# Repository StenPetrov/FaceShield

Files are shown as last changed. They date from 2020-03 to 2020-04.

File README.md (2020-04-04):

# FaceShield

This is a design for a lightweight face shield, made from laser-cut clear sheet plastic and a specialized 3D-printed screw. The design is suitable for fast production and is comfortable to wear with securely held elastic band.

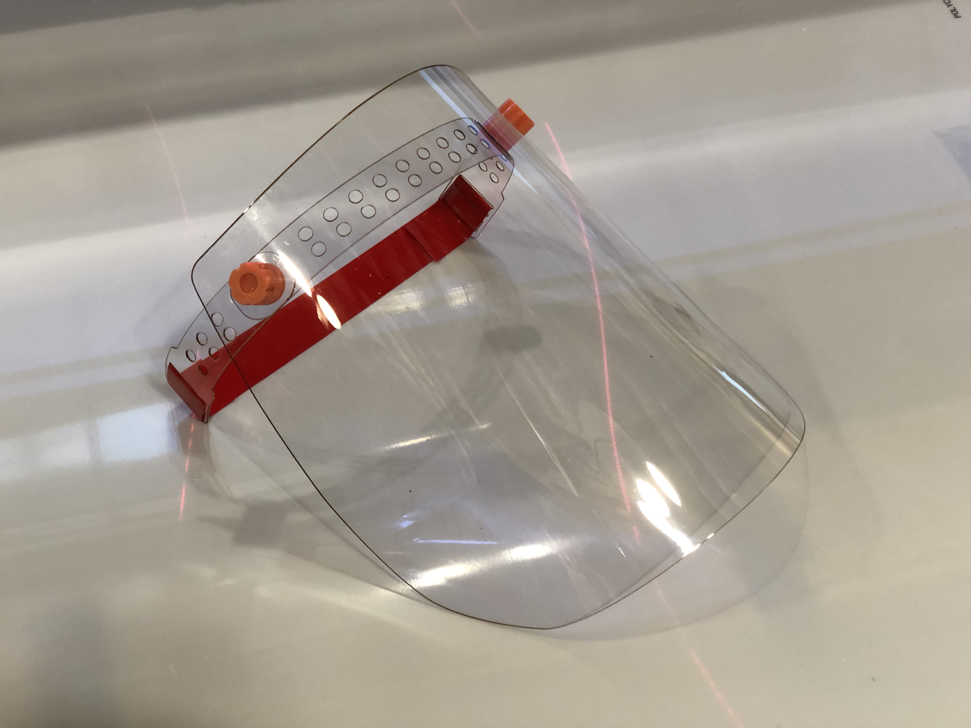
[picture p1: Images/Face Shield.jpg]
Face Shield


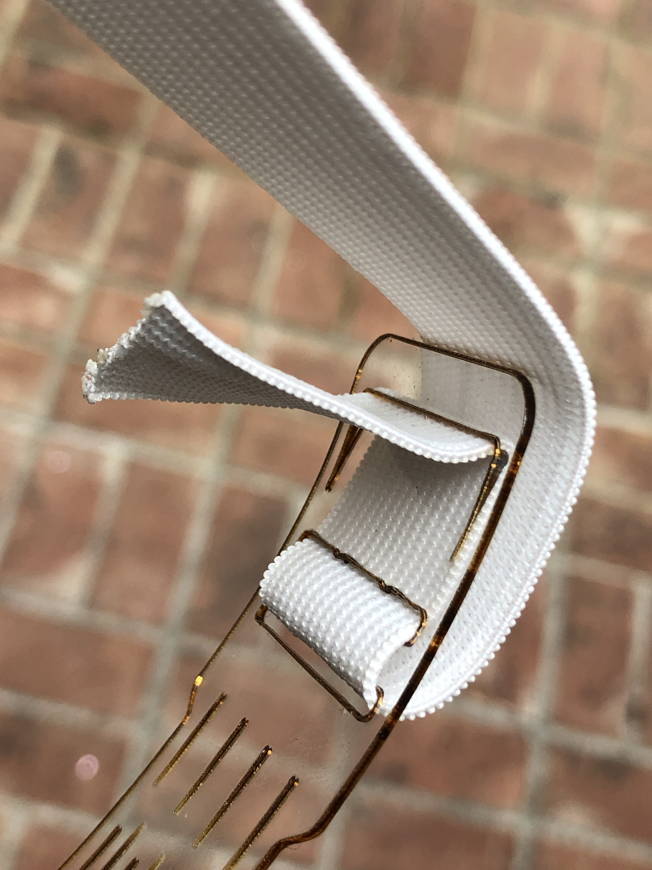
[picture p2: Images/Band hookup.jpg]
Elastic band


The shield was approved for use by Seattle Overlake hospital.

Popular [Prusa Face Shield](https://www.prusa3d.com/covid19/) requires 2+ hours to 3D print, with large nozzle and high speeds. It is comfortable to wear\* due to its wide band. There are designs with narrow head band, which print much faster (15-30 min) but aren't as comfortable with the narrow band.

**WARNING:** DO NOT CUT POLYCARBONATE OR ANY CHLORINE-CONTAINING PLASTICS WITHOUT PROPER VENTILATION. THE FUMES ARE TOXIC

Sheet plastic can be polystyrene or polycarbonate\*, 0.015" to 0.030"\* in thickness and 12" (30cm) square in size. Other materials and thicknesses may be usable. The sheet should comply nicely with the curved shape but not fold freely.
PETG\* 3D-printed specialized screw can be replaced with rivets if a 3D printer is not available.
1" (25mm) elastic band, about 12" (30cm) is used to keep the face shield tight, yet comfortable.
1" rescue tape is used for the elastic band as it is readily available, non-porous and temperature resistant so it is easy to clean in a dishwasher or with bleach.

Feel free to fork or contribute in any way. Feedback is welcome.

---
\*: tested

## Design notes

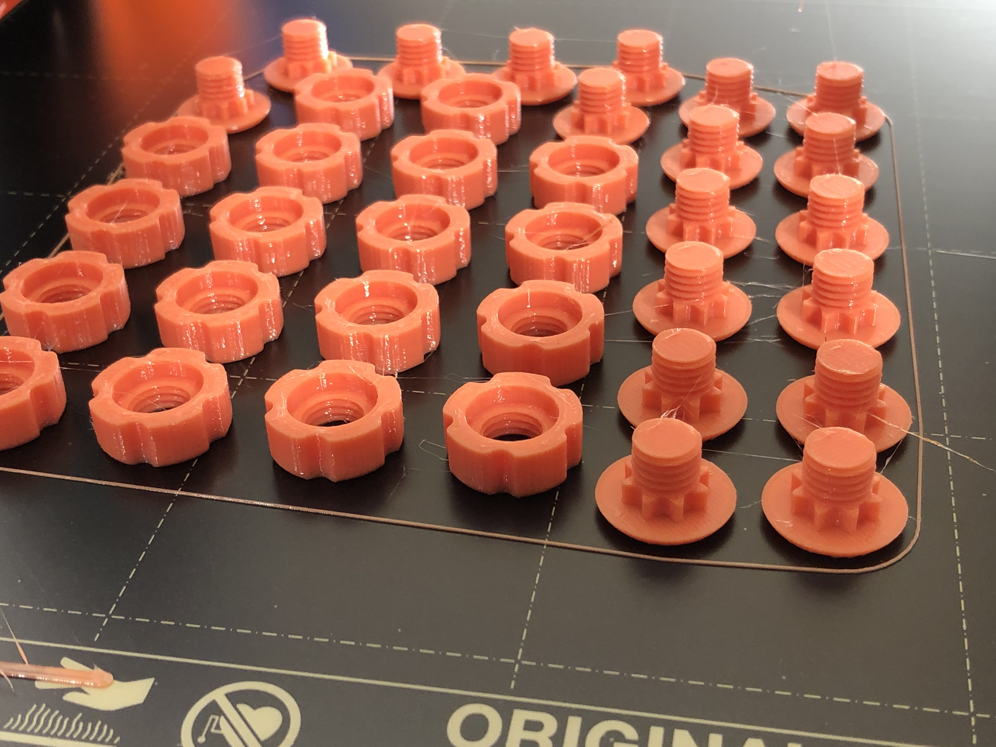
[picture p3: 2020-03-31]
Images/Specialized Screw.jpg

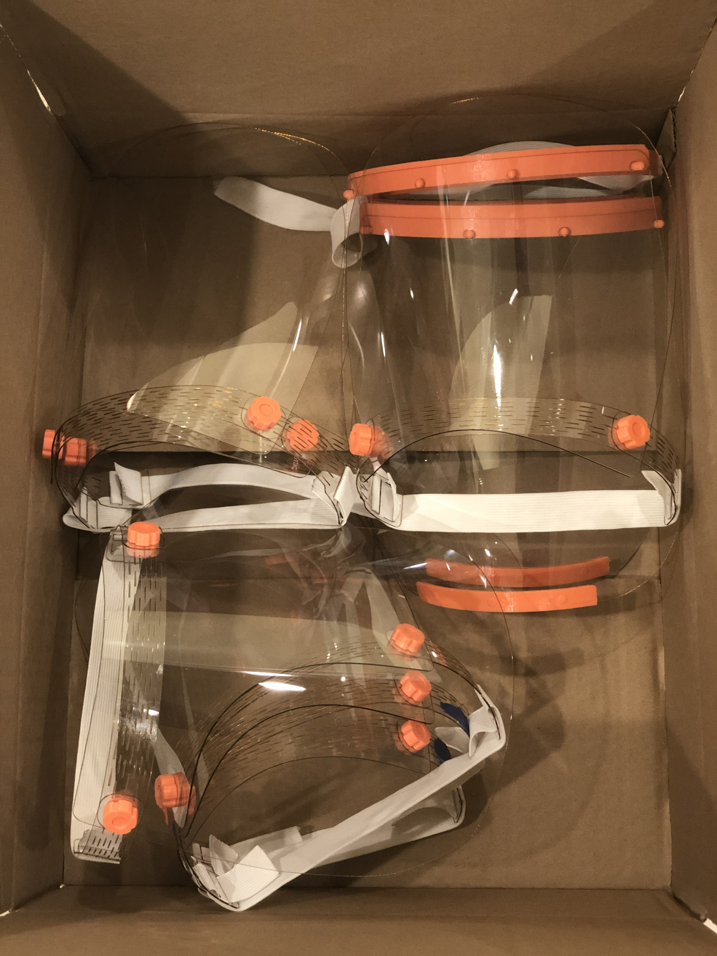
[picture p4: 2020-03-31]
Images/Package.jpg

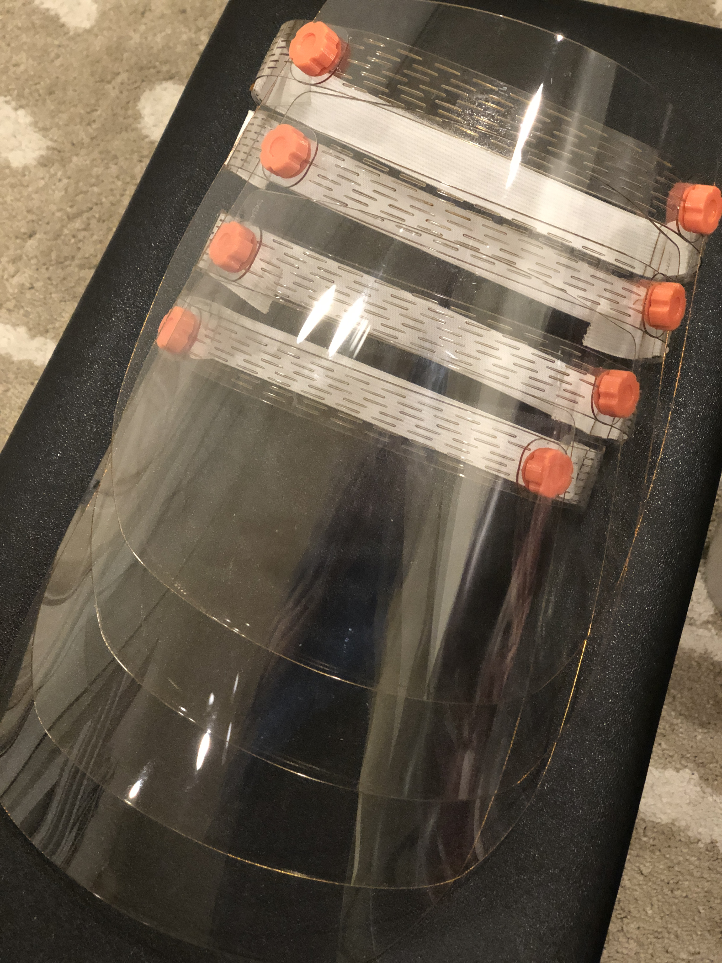
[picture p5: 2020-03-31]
Images/Four Face Shields.jpg

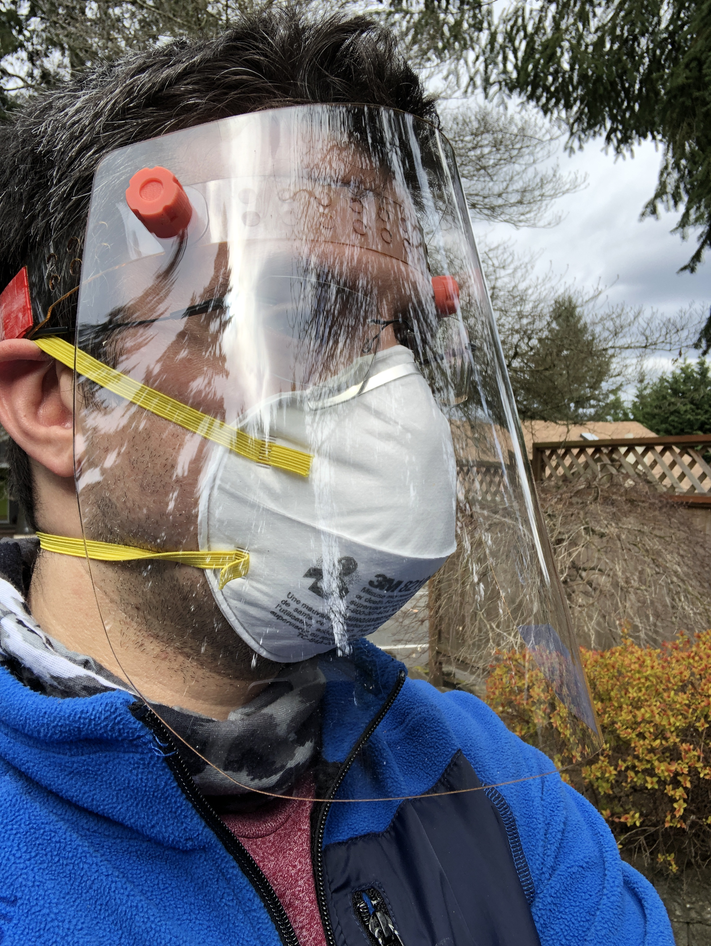
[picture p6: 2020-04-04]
Images/Worn with mask and glasses 2.jpg

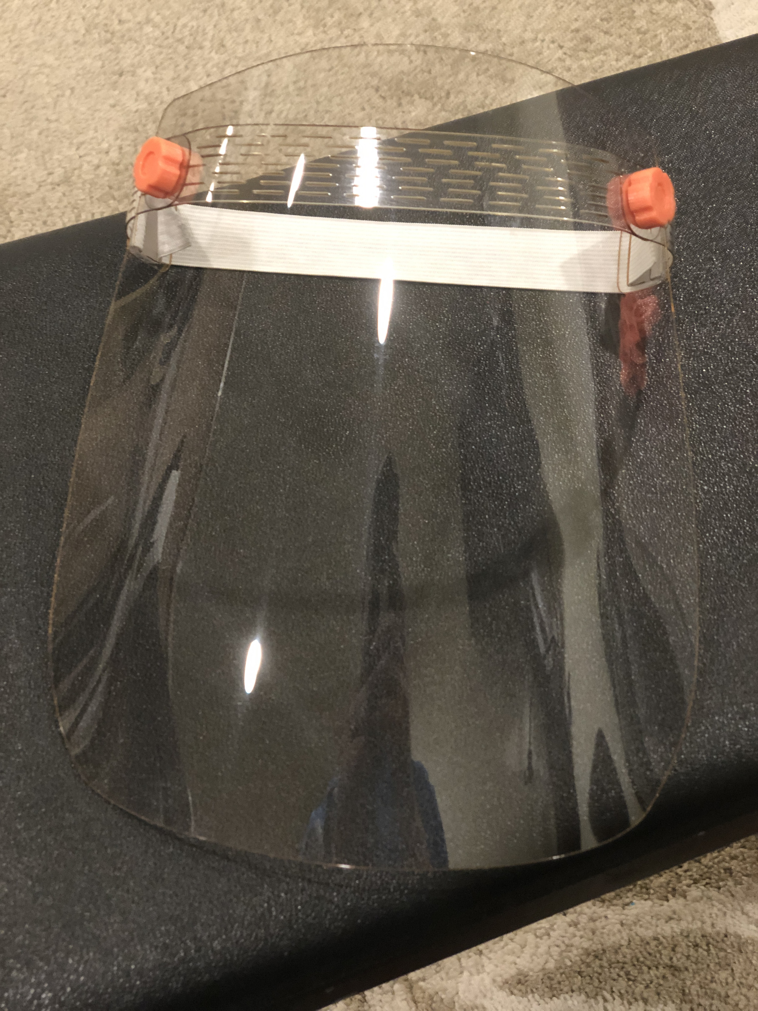
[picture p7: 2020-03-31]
Images/Face Shield Prototype.jpg

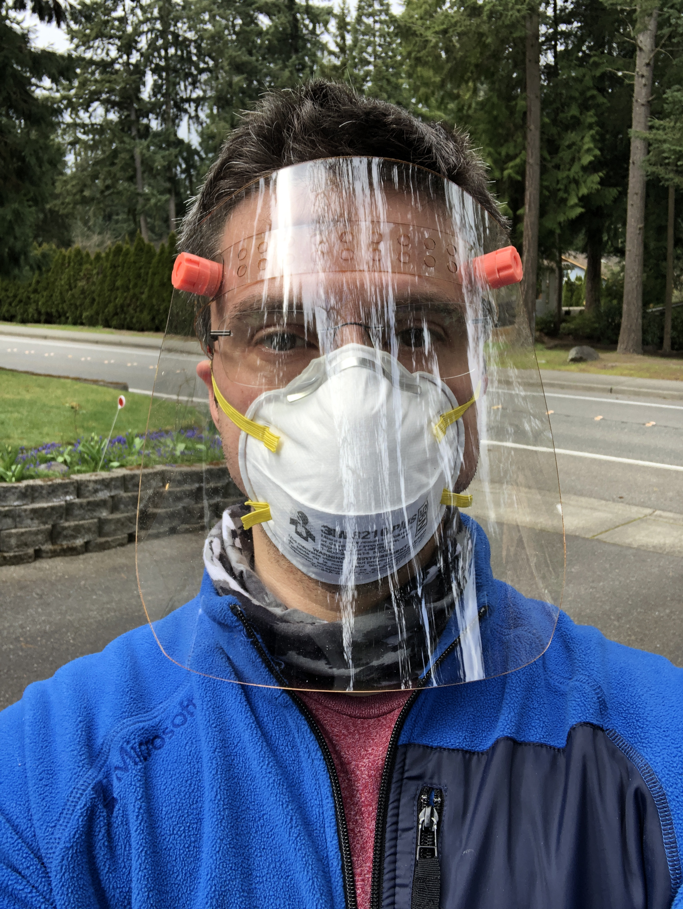
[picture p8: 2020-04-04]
Images/Worn with mask and glasses 1.jpg

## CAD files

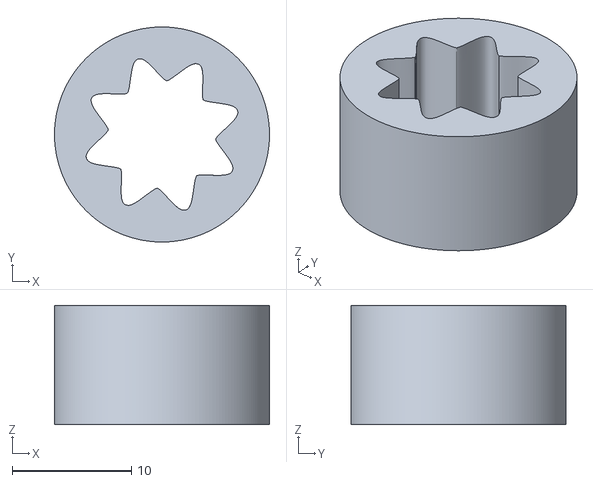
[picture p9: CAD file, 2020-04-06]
3D Parts/Rev 2/10 mm Spacer.stl
18.0 x 18.0 x 10.0

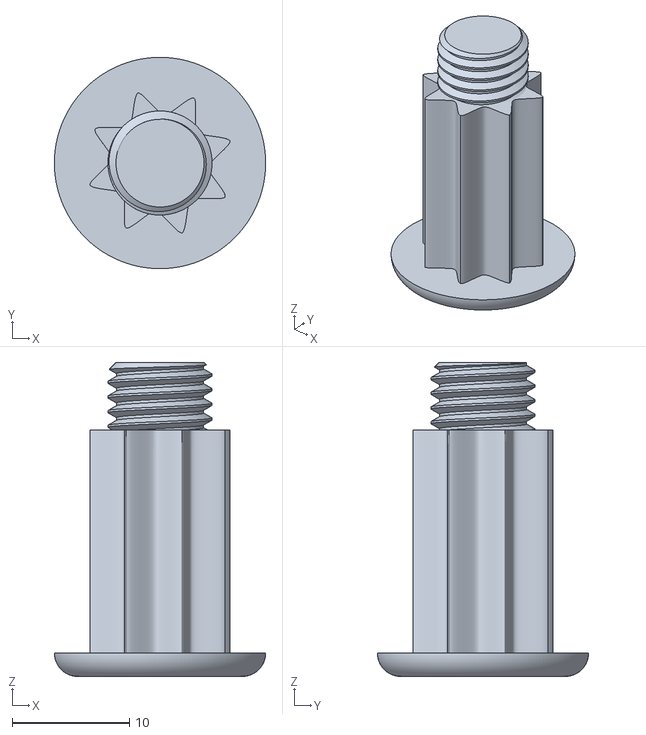
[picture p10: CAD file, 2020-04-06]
3D Parts/Rev 2/15 mm Insert.stl
18.0 x 18.0 x 26.8

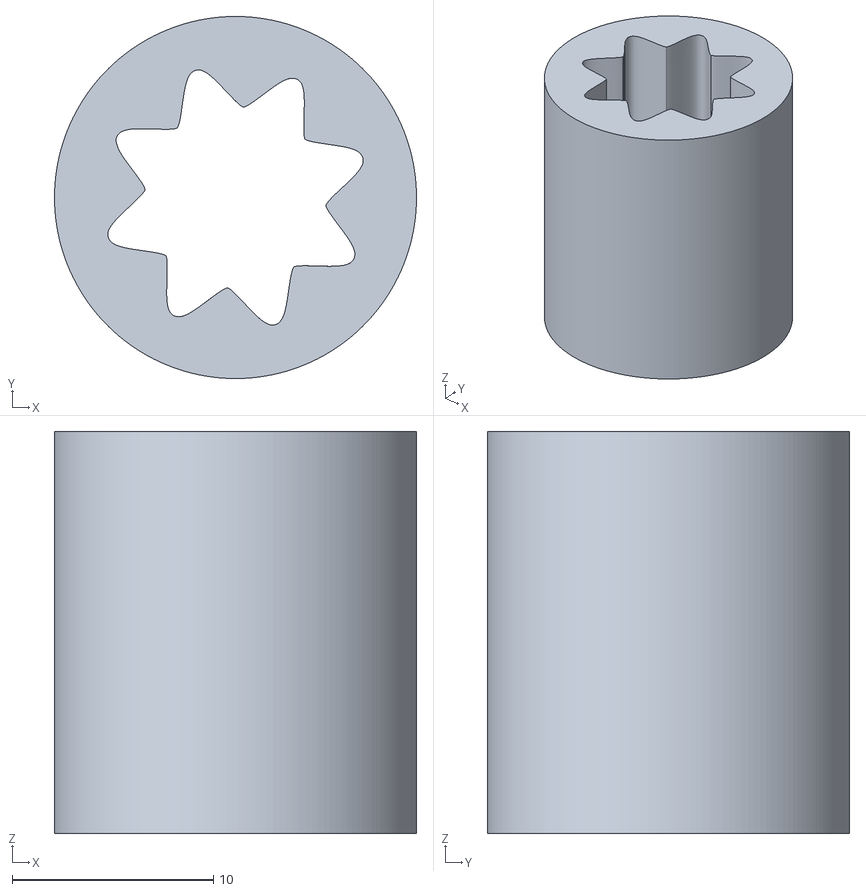
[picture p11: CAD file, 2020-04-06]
3D Parts/Rev 2/20 mm Spacer.stl
18.0 x 18.0 x 20.0

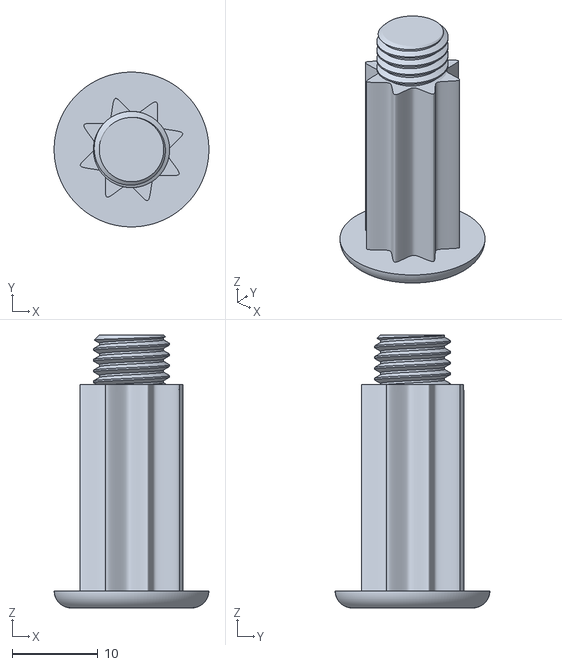
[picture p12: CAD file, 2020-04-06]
3D Parts/Rev 2/20 mm Insert.stl
18.0 x 18.0 x 31.7

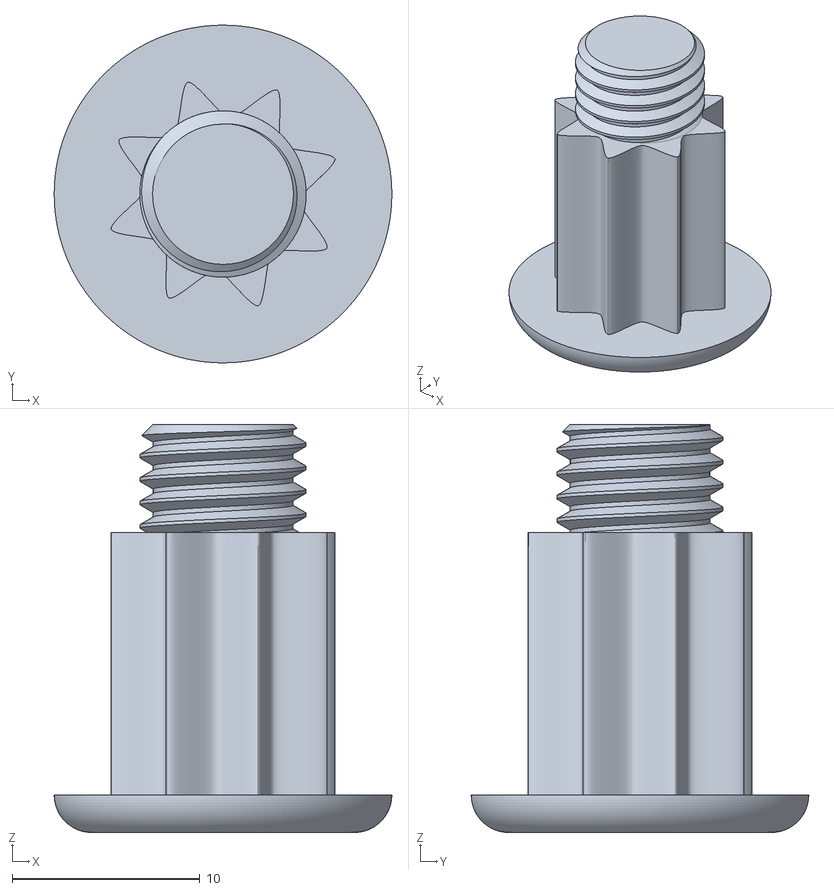
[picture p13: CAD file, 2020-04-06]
3D Parts/Rev 2/10 mm Insert.stl
18.0 x 18.0 x 21.8

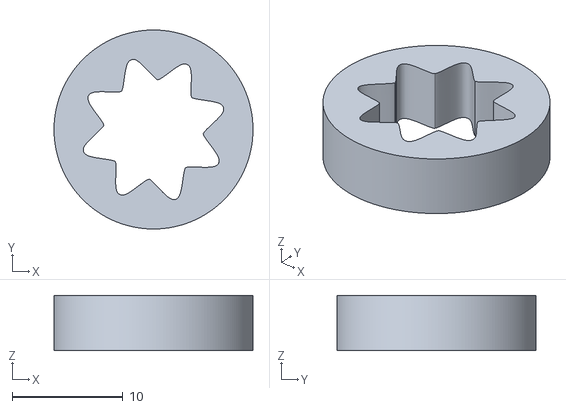
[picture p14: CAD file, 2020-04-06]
3D Parts/Rev 2/5 mm Spacer.stl
18.0 x 18.0 x 5.00

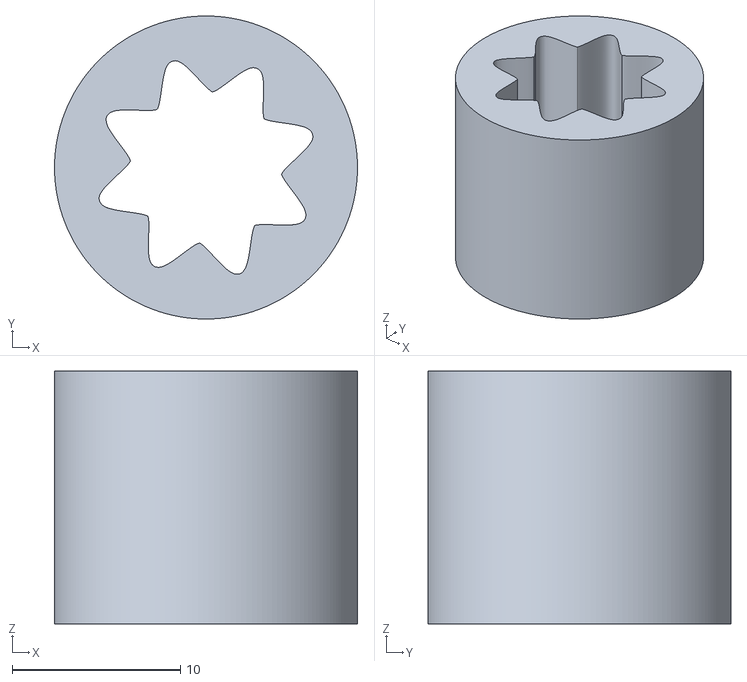
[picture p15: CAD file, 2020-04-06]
3D Parts/Rev 2/15 mm Spacer.stl
18.0 x 18.0 x 15.0

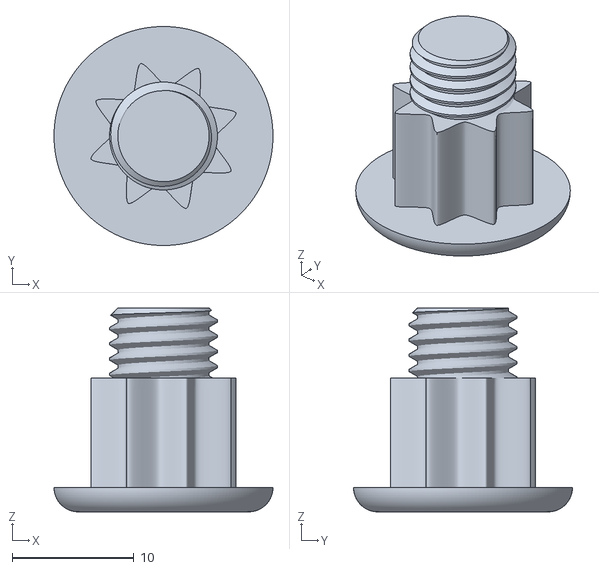
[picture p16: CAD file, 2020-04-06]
3D Parts/Rev 2/5 mm Insert.stl
18.0 x 18.0 x 16.8

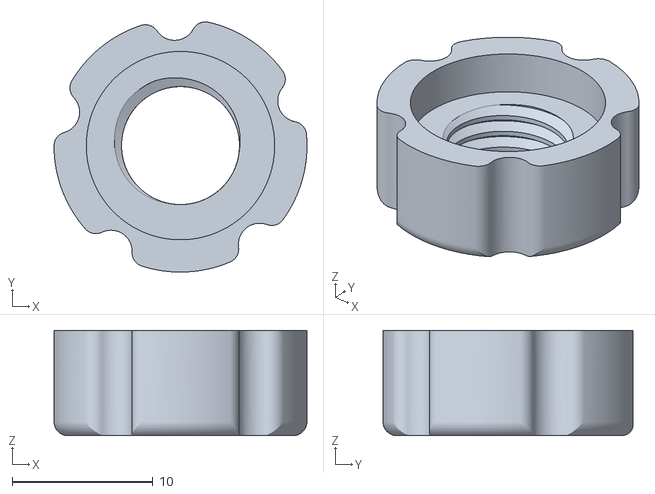
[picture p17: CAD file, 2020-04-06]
3D Parts/Rev 2/Nut - 8 pcnt tolerance.stl
18.0 x 17.8 x 7.50

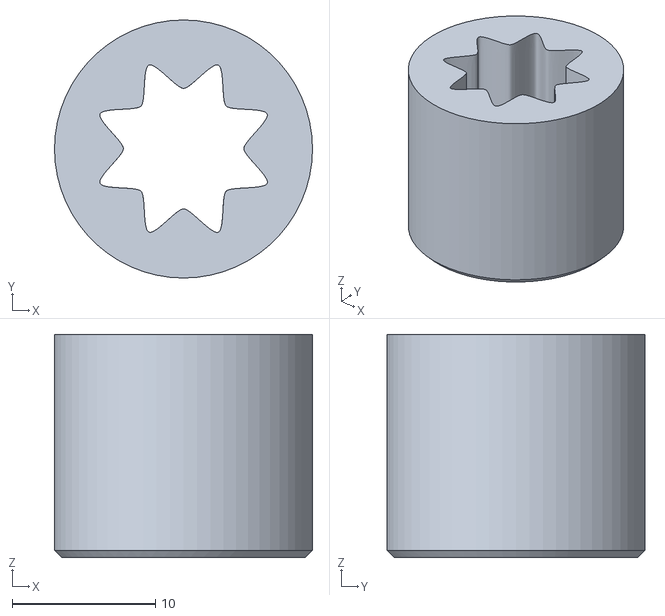
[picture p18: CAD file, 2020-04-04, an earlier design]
3D Parts/Rev 1/Spacer 15mm.stl
18.0 x 18.0 x 15.6

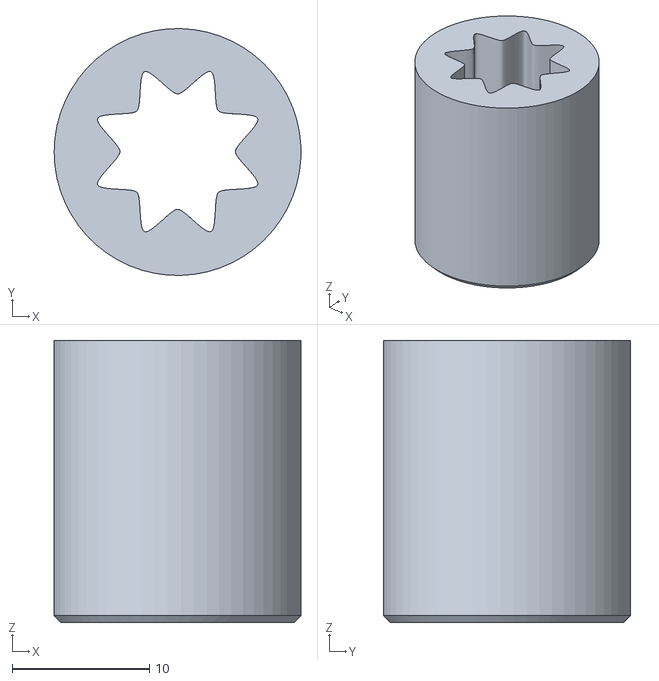
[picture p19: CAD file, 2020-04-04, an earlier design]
3D Parts/Rev 1/Spacer 20mm.stl
18.0 x 18.0 x 20.6

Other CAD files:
Simple Face Shield for Laser.dxf
Petrov Face Shield rev3 on 12x12in.dxf
3D Parts/Rev 2/Nut - 12 pcnt tolerance.stl
3D Parts/Rev 2/Nut - 10 pcnt tolerance.stl
3D Parts/Rev 2/Nut - no tolerance.stl
3D Parts/Rev 2/Nut - 5 pcnt tolerance.stl
Petrov Face Shield on 12x12in.dxf
3D Parts/Rev 1/Inside Screw for Spacer 10mm.stl
3D Parts/Rev 1/Inside Screw for Spacer 15mm.stl
3D Parts/Rev 1/Inside Screw for Spacer 20mm.stl
3D Parts/Rev 1/Inside Screw.stl
3D Parts/Rev 1/Outside Nut.stl
3D Parts/Rev 1/Screw and Nut x18.3mf
3D Parts/Rev 1/Screw and Nut x8.3mf
3D Parts/Rev 1/Spacer 10mm.stl
3D Parts/Rev 2/Petrov Face Shield v6.f3d

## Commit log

2020-03-31 Initial Commit
    Face shield: Lightburn, dxf and svg versions of the design. Lightburn power settings are for 100W machine cutting 0.030" Lexan.
    Customized screw: STL files, 3mf files from PrusaSlicer and gcode for PETG as printed on a Prusa i3 mk3s
    [Inside Screw.stl, Outside Nut.stl, Petrov Face Shield on 12x12in.dxf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]
2020-04-01 Adding spacers so the shield can be more comfortable with glasses
    [Inside Screw for Spacer 10mm.stl, Inside Screw for Spacer 15mm.stl, Inside Screw for Spacer 20mm.stl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]
2020-04-03 rev3: Wider shield, slight curve on top, slightly smaller vent holes, a notch to keep the strap more secure
    [Petrov Face Shield rev3 on 12x12in.dxf]
2020-04-04 Tweaks to STLs: nut scale, chamfer and flip; spacer scale
    [Outside Nut.stl, Spacer 10mm.stl, Spacer 15mm.stl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]
2020-04-04 rev3: wider shield (max for 4ft sheet)
    [Petrov Face Shield rev3 on 12x12in.dxf]
2020-04-06 Rev 2 - Tweaked STLs with better tolerances for 3D printing (#1)
    * Here are my Rev 2 suggestions. I also added several nuts with different I.D. tolerances to make things easier for a variety of printers.
    * Centered all the STLs at 0,0 and flipped the nuts 180 so they are facing the right direction from the start.
    * Fixed dimenstion based on discussion and added a 5% tolerance nut.
    [10 mm Insert.stl, 10 mm Spacer.stl, 15 mm Insert.stl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]
2020-04-09 Simple Laser-cut Face Shield rev0
    [Simple Face Shield for Laser.dxf]
